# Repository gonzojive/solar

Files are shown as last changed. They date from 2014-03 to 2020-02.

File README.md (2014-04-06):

Introduction
=====

The cost of solar panels has dropped to below $1 per watt.  However, the cost
per installed watt is significantly higher, at over
[$5 / watt in California](http://www.californiasolarstatistics.ca.gov/) in 2014.
This project attempts to provide open source versions of the power electronics in
photovolatic systems, in the hopes that providing such open source hardware
will drive down the price of these components.

The first project is the design of a Maximum Power Point Tracker for a single solar
panel.  A commercial example of this product is the
[SolarEdge series of power optimizers](http://www.solaredge.us/groups/us/powerbox-power-optimizer).

To be continued...

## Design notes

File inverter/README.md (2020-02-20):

# Tim Nolan's grid-tie inverter

The files in this directory were originally developed by Tim Nolan.  I found
them on
[his web site](http://www.timnolan.com/index.php?page=solar-grid-intertie-inverter).

The website is no longer available, and I cannot confirm the license of the original code at this point.

## Project Technical Description

An inverter is basically an electronic device that takes a DC input voltage and
converts it to an AC output voltage. My design takes a 12V DC input from my
solar panels (two 50w panels in parallel) and converts it 120V AC at 60Hz which
is the power that most home appliances use. A grid-intertie inverter connects up
to and external AC power system and matches it's internal AC sinewave to the
external AC sinewave to allow the inverter to feed power into the external
system. My inverter design also includes a maximum power point tracking
algorithm to maximize the power drawn from the solar panel. The inverter uses 4
MOSFETs in a full bridge configuration to convert the input DC to a low voltage
AC. The low voltage AC is converted to high voltage AC by a toroidal transformer
with a 1:30 ratio. The high voltage AC is rectified by 4 diodes in a full bridge
configuration. The resulting waveform is smoothed by an inductor and capacitor
filter and then converted to an AC sinewave by the final 4 MOSFET switches. A
relay is used to connect the generated AC to the external AC. I used an Atmel
AT90PWM3B processor to control the inverter. This processor has some nice
feature that make is well suited to digital power control. Please see the
hardware description and software comments for a more detailed explanation of
the project.

## Schematics

These schematics were created with EagleCAD v4.16r1. I've included the Eagle
schematics and the pdf version of the schematic and the board layout file. This
project is divided into two printed circuit board. The low voltage board (12v
DC) is the inverter control board. The high voltage board (120v AC) is the
inverter power board.

Inverter Control Board:

- `inverter_control.sch`
- `inverter_control.brd`
- `inveter_control.pdf`
- `inverter_control_parts.txt`

Inverter Power Board:

- `inverter_power.sch`
- `inverter_power.brd`
- `inverter_power.pdf`
- `inverter_power_parts.txt`

## Hardware Description

### Low Voltage Section (inverter\_control.sch)

The inverter is divided into two printed circuit board. The `inverter_control.sch`
describes the low voltage circuit board. U4 is the microprocessor. It is an
Atmel AT90PWM3B. I choose the AT90PWM3B because it has a very power and flexible
PWM control section that they call a Power Stage Controller. The processor has a
serial interface to talk to the PC using a MAX232A (IC2) and 9 pin D connector
(X5). The ISP programming connector for the JTAGICE mk II is the 6 pin .1"
(SV4). X4 and Q5 are for PWM fan speed control but this feature is not
implemented yet. S1 dipswitch is for user software configuration and
debugging. U3 is an LM35 analog temperature sensor. This temperature sensor is
mounted next to the MOSFETs on the heatsink. It is used by software to make sure
the MOSFETs don't overheat. IC5 is a 74LS32 Quad OR gate and IC1 is a 74LS14 Hex
Inverter. These gates are used to read back the zero crossing signals from the
high power board. The OR gate is connected to a Timer Input Capture pin so the
length of the zero crossing signal can be calculated. Q1, Q2, Q3 and Q4 are the
MOSFETs (IRLIZ44 N-fets) that make up the full bridge switcher. This is the
heart of the low voltage section. The full bridge switcher takes the DC input
voltage from the solar panels and switches it into high frequency AC to pass on
to the transformer to generate high voltage AC. The MOSFETs are driven by two
IR2104s MOSFET drivers (U1 and U2). The IR2104s use bootstrap capacitors C9 and
C10 to generate the voltages needed to drive the high side MOSFETs Q1 and
Q3. C14 and C15 are the large input capacitors used to smooth out the input
solar power. R32 and R33 make up the voltage divider to drop down the input
solar voltage so it can be read by the processor A/D. IC8 is a LT1787 that use
the current sensing resistor R30 to measure the input solar current. Using the
solar panel voltage and input current the processor can calculate the solar
panel wattage that is used in the Peak Power Tracking algorithm. IC9 is the
linear regulator used to generate 5V from the input solar voltage. SV1 is the
connector for the control and sensing signals to the inverter\_power pcb. X3 is
the connector for the high frequency low voltage AC generated by the full bridge
to the isolation tranformer primary. The transformer is a xxxx ferrite
toriod. The primary is wound with 3 turns of 16ga magnet wire. The secondary is
wound with 60 turns 20ga magnet wire which give the transformer a ratio of
1:20. The transformer also has two more isolated secondary windings of 4
turns. These generate two seperate isolated power supplies for the sensing
circuits on the inverter\_power pcb.

### High Voltage Section (inverter\_power.sch)

The inverter power pcb takes the high frequency high voltage AC from the
transformer and turns it into 120V AC power synced up to the external AC. There
are also isolated sections that sense the zero crossing and the voltage of the
external AC. The low voltage control and sensing signals to and from the
inverter control pcb go through a 16 pin ribbon cable to the SV1 connector. All
the low voltage signals to and from the inverter control board are isolated from
the high voltage AC on the inverter power board by optoisolators. The high
voltage high frequency AC from the transformer secondary comes in on connector
X1. It is snubbed by R14 and C25 and then rectified by 4 diodes in a bridge
configuration D22, D23, D24 and D25. The pcb also has an active rectifier with 4
MOSFETSs Q6, Q7, Q8 and Q9 but these are not used and not installed. Their
MOSFET drivers U8 and U9 and control signal optoisolators OK4A, OK4B and OK5B
are also not used and not installed. After the diode rectifer the signal is
snubbed again by D21, R19 and C32. Then it's smoothed by L2 ad C27. There are
also connectors X5 and X6 so that different values of inductor capacitor filters
can be experimented with. Normally at this point the high frequency and high
voltage AC signal from the transformer secondary would be rectified and smoothed
out to a high voltage DC value. In most inverter topologies this DC voltage
would be chopped and inverted into a 120V 60Hz AC sinewave by the MOSFETs in the
output bridge(Q10, Q11, Q12 and Q13). This means the output MOSFETs have to
switch at a very high frequency (>30kHz) to recreate a sinewave that can be
smoothed by the output filters. Because the MOSFETs are switching a high voltage
at a high switching rate I found in my experimentation that they get very hot. I
went back and did some more research and found a slightly different topology
that alleviated this problem. Instead of a constant duty cycle the low voltage
bridge varies the duty cycle of the high frequency AC in a 60Hz sine wave
pattern. After transformer voltage boost rectification and smoothing instead of
a constant high voltage DC you get a positive only 60Hz sinewave varying voltage
(insert oscilliscope image). Since most of the work of generating the sinewave
is already done the output bridge only as to switch at the 60Hz rate to unfold
the waveform to flip one half of it to negative (insert oscilliscope
picture). Since the output bridge is switching much slower it runs much
cooler. Once the 120V 60Hz AC is generated it can not be connected to the
external grid AC until it is matched in phase and voltage. The relay K1 keeps
the voltage isolated until the processor says it is correct. The output bridge
is driven by two MOSFET drivers U10 and U11. They are isolated from the low
voltage control signals by the optoisolators OK3A, OK3B and OK5A. The MOSFET
drivers and optos are powered by the isolated power supply generated by the
auxilary winding on the transformer AUX1. The winding is connected to X2 and
rectified filtered by B2 and C20. IC7 is the voltage regulator that generates
5v. To sync the interally generated AC to the external AC the zero crossing of
the external AC must be sensed. That's done by the two optoisolators OK2A and
OK2B. Two low voltage signals are generated that bracket the zero crossing of
the external AC. Measuring the external AC voltage and sending it back the
signal isolated to the low voltage side is tricky. I ended up using a small 8
pin Atmel microprocessor the ATtiny45. An isolated power supply was generated
using another isolated winding on the transformer AUX2. This comes in on
connector X4 and is rectified and filtered by B1 and C1. IC3 generates 5V that
is filtered by C11. This 5V is used to power IC4 which is the ATtiny45
microprocessor. SV2 is the programming connector and LED3 is the heartbeat
LED. The external AC is rectified by B3 so we get it all as a positive
signal. Then it is voltage divided and filtered by R10, R11 and C12 so the input
voltage is under 5v to be read by the processor A/D. The processor reads the
input voltage and calculates the RMS AC voltage (see the software listing
sw\_sensev5.c for how this is done). The value of the external AC RMS voltage is
then transmitted as a clocked serial signal through the optoisolators OK1A and
OK1B to get it to the main processor on the isolated low voltage control pcb.

## Software

The main processor for the inverter is an Atmel AT90PWM3B. I used the free
development system from Atmel AVR Studio 4 and installed the open source GCC
compiler package WinAVR. This has allowed me to write all my software for this
project in C using this free development enviroment. I did buy Atmel's JTAGICE
mk II that allows me to download, program and debug the processor in my system
using the in circuit programming port on the processor. I've included the source
code for the AT90PWM3B main processor and the small ATtiny45 processor that used
to read the AC voltage. Please see the comments in the code for explanation of
the inverter software.

AT90PWM3B Main Processor Source Code: `sinewave4v10.c`

ATtiny45 Auxilary Processor Source Code: `sw_sensev5.c`

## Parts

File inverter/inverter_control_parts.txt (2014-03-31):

Partlist

Exported from inverter_control.sch at  1/18/2009 01:41:28p

EAGLE Version 4.16r1 Copyright (c) 1988-2006 CadSoft

Part     Value           Device           Package    Library          Sheet

C1       .1uF            C2,5-3           C2.5-3     capacitor-wima   1
C2       .1uF            C2,5-3           C2.5-3     capacitor-wima   1
C3       .1uF            C2,5-3           C2.5-3     capacitor-wima   1
C4       .1uF            C2,5-3           C2.5-3     capacitor-wima   1
C5       .1uF            C2,5-3           C2.5-3     capacitor-wima   1
C6       .1uF            C2,5-3           C2.5-3     capacitor-wima   1
C7       .1uF            C2,5-3           C2.5-3     capacitor-wima   1
C8       10uF            C5/3.5           C5B3.5     capacitor-wima   1
C9       .1uF            C2,5-3           C2.5-3     capacitor-wima   1
C10      .1uF            C2,5-3           C2.5-3     capacitor-wima   1
C11      .1uF            C2,5-3           C2.5-3     capacitor-wima   1
C12      .1uF            C2,5-3           C2.5-3     capacitor-wima   1
C14      100uF           CPOL-USE5-13     E5-13      rcl              1
C15      100uF           CPOL-USE5-13     E5-13      rcl              1
C16      ,01uF           C2,5-3           C2.5-3     capacitor-wima   1
C17      .1uF            C2,5-3           C2.5-3     capacitor-wima   1
C18      .1uF            C2,5-3           C2.5-3     capacitor-wima   1
D1       1N4148          1N4148           DO35-10    diode            1
D2       1N4148          1N4148           DO35-10    diode            1
IC1      74LS14N         74LS14N          DIL14      74xx-us          1
IC2      MAX232          MAX232           DIL16      maxim            1
IC5      74LS32N         74LS32N          DIL14      74xx-us          1
IC8      LT1787          LT1787           SO08       SolarFlasher     1
IC9      5V              78XXS            78XXS      v-reg            1
LED1     GRN             LED3MM           LED3MM     led              1
LED2     RED             LED3MM           LED3MM     led              1
Q1       IRLIZ44         PMOSFET_NTO220BV TO220BV    transistor-power 1
Q2       IRLIZ44         PMOSFET_NTO220BV TO220BV    transistor-power 1
Q3       IRLIZ44         PMOSFET_NTO220BV TO220BV    transistor-power 1
Q4       IRLIZ44         PMOSFET_NTO220BV TO220BV    transistor-power 1
Q5       2N3904          2N3904           TO92       transistor-npn   1
R1       10k             R-US_0207/10     0207/10    rcl              1
R2       1k              R-US_0207/10     0207/10    rcl              1
R3       1k              R-US_0207/10     0207/10    rcl              1
R4       1k              R-US_0207/10     0207/10    rcl              1
R5       10              R-US_0207/10     0207/10    rcl              1
R30      .005            R-US_0207/12     0207/12    rcl              1
R31      3k              R-US_0207/10     0207/10    rcl              1
R32      3k              R-US_0207/10     0207/10    rcl              1
R33      1k              R-US_0207/10     0207/10    rcl              1
R34      1k              R-US_0207/10     0207/10    rcl              1
S1       DIP2            SD4-02           SD4-02     switch-dil       1
SV1      DUAL8           MA08-2           MA08-2     con-lstb         1
SV4      DUAL3           MA03-2           MA03-2     con-lstb         1
U1       IR2106          IR2103           DIL08      irf-2            1
U2       IR2106          IR2103           DIL08      irf-2            1
U3       LM35            LM35             TO220S     inverter         1
U4       AT90PWM3B_DIP32 AT90PWM3B_DIP32  DIL32      inverter         1
X2       PIN2            W237-02P         W237-132   con-wago-508     1
X3       PIN2            W237-02P         W237-132   con-wago-508     1
X4       22-23-2021      22-23-2021       22-23-2021 con-molex        1
X5       SERIAL          F09HP            F09HP      inverter         1

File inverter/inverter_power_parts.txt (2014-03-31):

Partlist

Exported from inverter_power.sch at  1/18/2009 01:45:12p

EAGLE Version 4.16r1 Copyright (c) 1988-2006 CadSoft

Part     Value          Device           Package  Library          Sheet

B1       DIP4           B-DIL            B-DIL    rectifier        1
B2       DIP4           B-DIL            B-DIL    rectifier        1
B3       DIP4           B-DIL            B-DIL    rectifier        1
C1       100uF          CPOL-USE5-10.5   E5-10,5  rcl              1
C2       .1uF           C2,5-3           C2.5-3   capacitor-wima   1
C3       .1uF           C2,5-3           C2.5-3   capacitor-wima   1
C4       .1uF           C2,5-3           C2.5-3   capacitor-wima   1
C11      10uF           C2,5-3           C2.5-3   capacitor-wima   1
C12      .1uF           C2,5-3           C2.5-3   capacitor-wima   1
C13      .1uF           C2,5-3           C2.5-3   capacitor-wima   1
C19      10uF           C2,5-3           C2.5-3   capacitor-wima   1
C20      100uF          CPOL-USE5-10.5   E5-10,5  rcl              1
C25      .01uF          C5/4.5           C5B4.5   capacitor-wima   1
C27      2uF            C22/8            C22.5B8  capacitor-wima   1
C28      .1uF           C2,5-3           C2.5-3   capacitor-wima   1
C29      .1uF           C2,5-3           C2.5-3   capacitor-wima   1
C30      .1uF           C2,5-3           C2.5-3   capacitor-wima   1
C31      .1uF           C2,5-3           C2.5-3   capacitor-wima   1
C32      .01uF          C5/4.5           C5B4.5   capacitor-wima   1
C34      .1uF           C2,5-3           C2.5-3   capacitor-wima   1
C35      .1uF           C2,5-3           C2.5-3   capacitor-wima   1
C37      .1uF           C2,5-3           C2.5-3   capacitor-wima   1
C38      .1uF           C2,5-3           C2.5-3   capacitor-wima   1
C39      .1uF           C2,5-3           C2.5-3   capacitor-wima   1
C40      .1uF           C2,5-3           C2.5-3   capacitor-wima   1
D3       1N4004         1N4004           DO41-10  diode            1
D4       1N4004         1N4004           DO41-10  diode            1
D17      1N4148         1N4148           DO35-10  diode            1
D18      1N4148         1N4148           DO35-10  diode            1
D19      1N4148         1N4148           DO35-10  diode            1
D20      1N4148         1N4148           DO35-10  diode            1
D21      MUR150RL       MUR150RL         DO41-10  diode            1
D22      FES08AT        FES08AT          DO220S   diode            1
D23      FES08AT        FES08AT          DO220S   diode            1
D24      FES08AT        FES08AT          DO220S   diode            1
D25      FES08AT        FES08AT          DO220S   diode            1
D26      1N4148         1N4148           DO35-10  diode            1
F1       5A             TR5              TR5      fuse             1
F2       5A             TR5              TR5      fuse             1
IC3      5V             78XXS            78XXS    v-reg            1
IC4      TINY45         TINY22P          DIL08    atmel            1
IC7      5V             78XXS            78XXS    v-reg            1
K1       NA             NA               NA       relay            1
L2       400uH          L-USTJ6-U1       TJ6-U1   rcl              1
LED3     GRN            LED3MM           LED3MM   led              1
OK1      HCPL2630       HCPL2630         DIL08    optocoupler      1
OK2      HCPL2630       HCPL2630         DIL08    optocoupler      1
OK3      HCPL2630       HCPL2630         DIL08    optocoupler      1
OK4      HCPL2630       HCPL2630         DIL08    optocoupler      1
OK5      HCPL2630       HCPL2630         DIL08    optocoupler      1
Q6       IRFI740        PMOSFET_NTO220BV TO220BV  transistor-power 1
Q7       IRFI740        PMOSFET_NTO220BV TO220BV  transistor-power 1
Q8       IRFI740        PMOSFET_NTO220BV TO220BV  transistor-power 1
Q9       IRFI740        PMOSFET_NTO220BV TO220BV  transistor-power 1
Q10      IRFI740        PMOSFET_NTO220BV TO220BV  transistor-power 1
Q11      IRFI740        PMOSFET_NTO220BV TO220BV  transistor-power 1
Q12      IRFI740        PMOSFET_NTO220BV TO220BV  transistor-power 1
Q13      IRFI740        PMOSFET_NTO220BV TO220BV  transistor-power 1
R4       10k            R-US_0207/10     0207/10  rcl              1
R5       330            R-US_0207/10     0207/10  rcl              1
R6       4.7k           R-US_0207/10     0207/10  rcl              1
R7       4.7k           R-US_0207/10     0207/10  rcl              1
R8       4.7k           R-US_0207/10     0207/10  rcl              1
R9       1k             R-US_0207/10     0207/10  rcl              1
R10      100k           R-US_0207/10     0207/10  rcl              1
R11      2k             R-US_0207/10     0207/10  rcl              1
R12      20K            R-US_0207/10     0207/10  rcl              1
R13      20K            R-US_0207/10     0207/10  rcl              1
R14      10k            R-US_0617/5V     0617V    rcl              1
R15      330            R-US_0207/10     0207/10  rcl              1
R16      330            R-US_0207/10     0207/10  rcl              1
R17      330            R-US_0207/10     0207/10  rcl              1
R18      330            R-US_0207/10     0207/10  rcl              1
R19      10k            R-US_0617/5V     0617V    rcl              1
R20      4.7K           R-US_0207/10     0207/10  rcl              1
R21      4.7K           R-US_0207/10     0207/10  rcl              1
R22      4.7K           R-US_0207/10     0207/10  rcl              1
R23      4.7K           R-US_0207/10     0207/10  rcl              1
R24      4.7k           R-US_0207/10     0207/10  rcl              1
R25      330            R-US_0207/10     0207/10  rcl              1
R26      4.7K           R-US_0207/10     0207/10  rcl              1
R27      330            R-US_0207/10     0207/10  rcl              1
R28      4.7K           R-US_0207/10     0207/10  rcl              1
R29      330            R-US_0207/10     0207/10  rcl              1
SV1      DUAL8          MA08-2           MA08-2   con-lstb         1
SV2      DUAL3          MA03-2           MA03-2   con-lstb         1
U8       IR2110         IR2103           DIL08    irf-2            1
U9       IR2110         IR2103           DIL08    irf-2            1
U10      IR2110         IR2103           DIL08    irf-2            1
U11      IR2110         IR2103           DIL08    irf-2            1
X1       PIN2           W237-02P         W237-132 con-wago-508     1
X2       PIN2           W237-02P         W237-132 con-wago-508     1
X3       PIN3           W237-3E          W237-3E  con-wago-508     1
X4       PIN2           W237-02P         W237-132 con-wago-508     1
X5       PIN2           W237-02P         W237-132 con-wago-508     1
X6       PIN2           W237-02P         W237-132 con-wago-508     1

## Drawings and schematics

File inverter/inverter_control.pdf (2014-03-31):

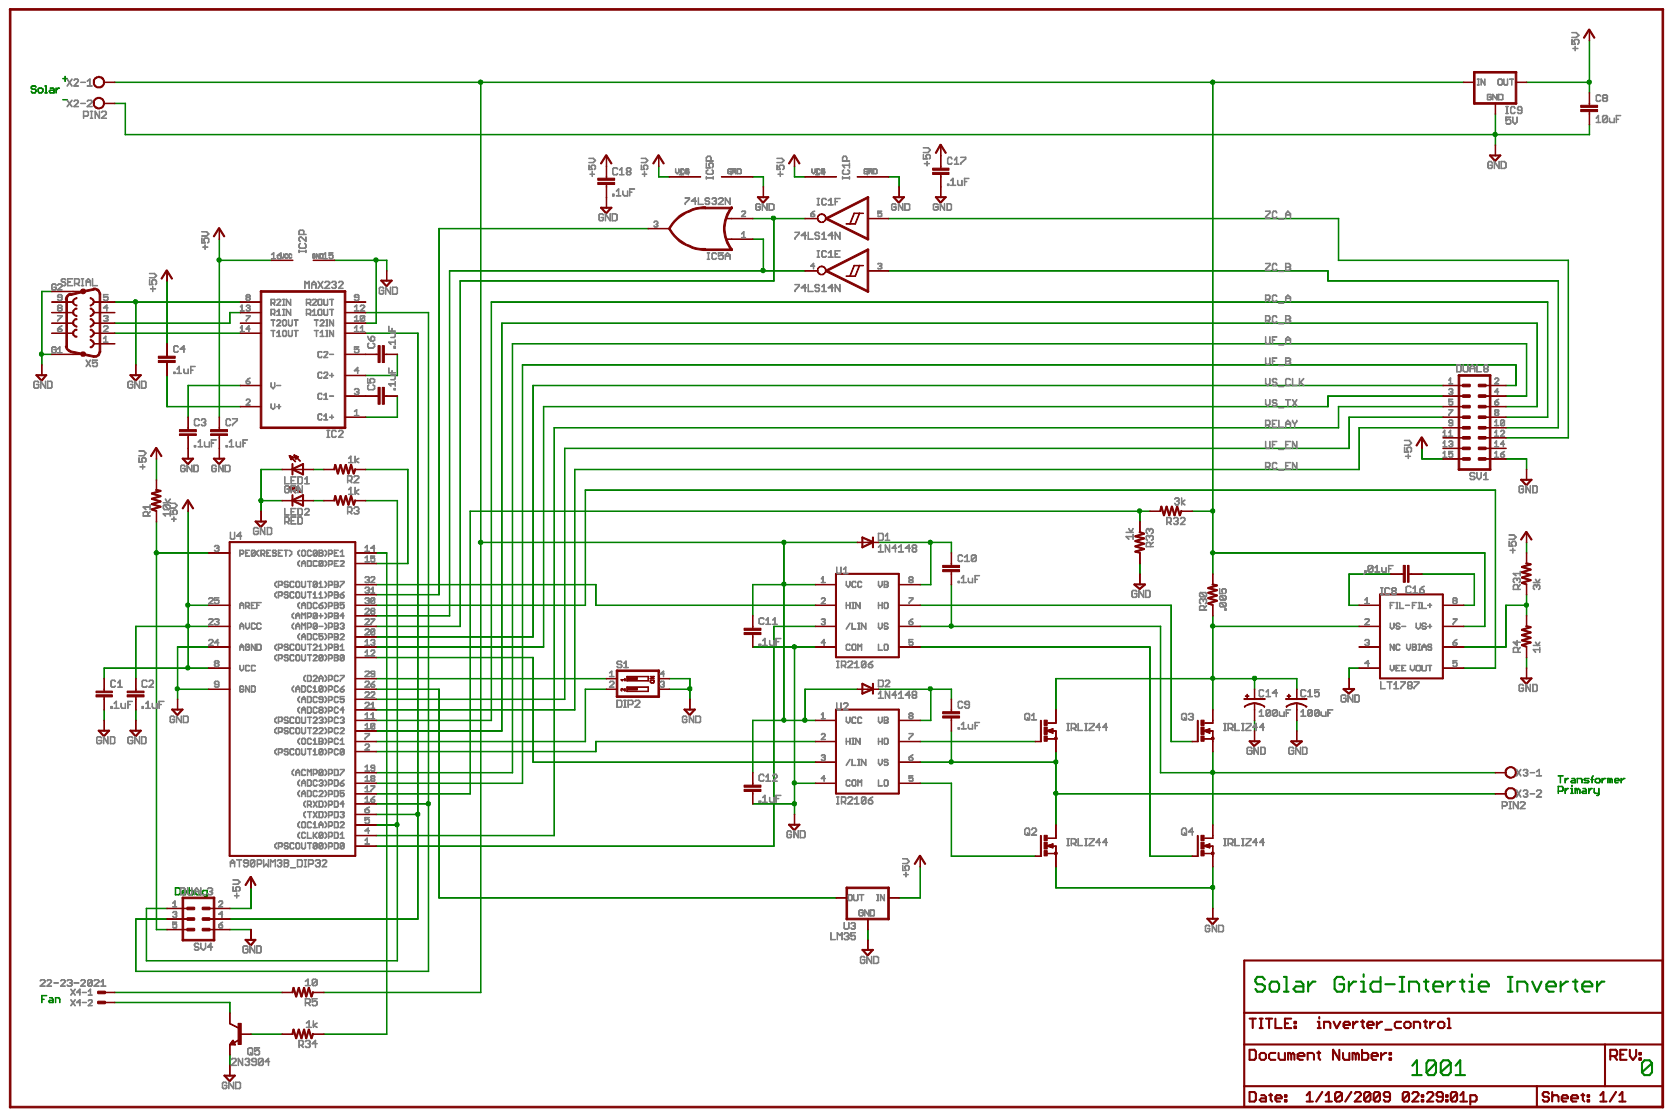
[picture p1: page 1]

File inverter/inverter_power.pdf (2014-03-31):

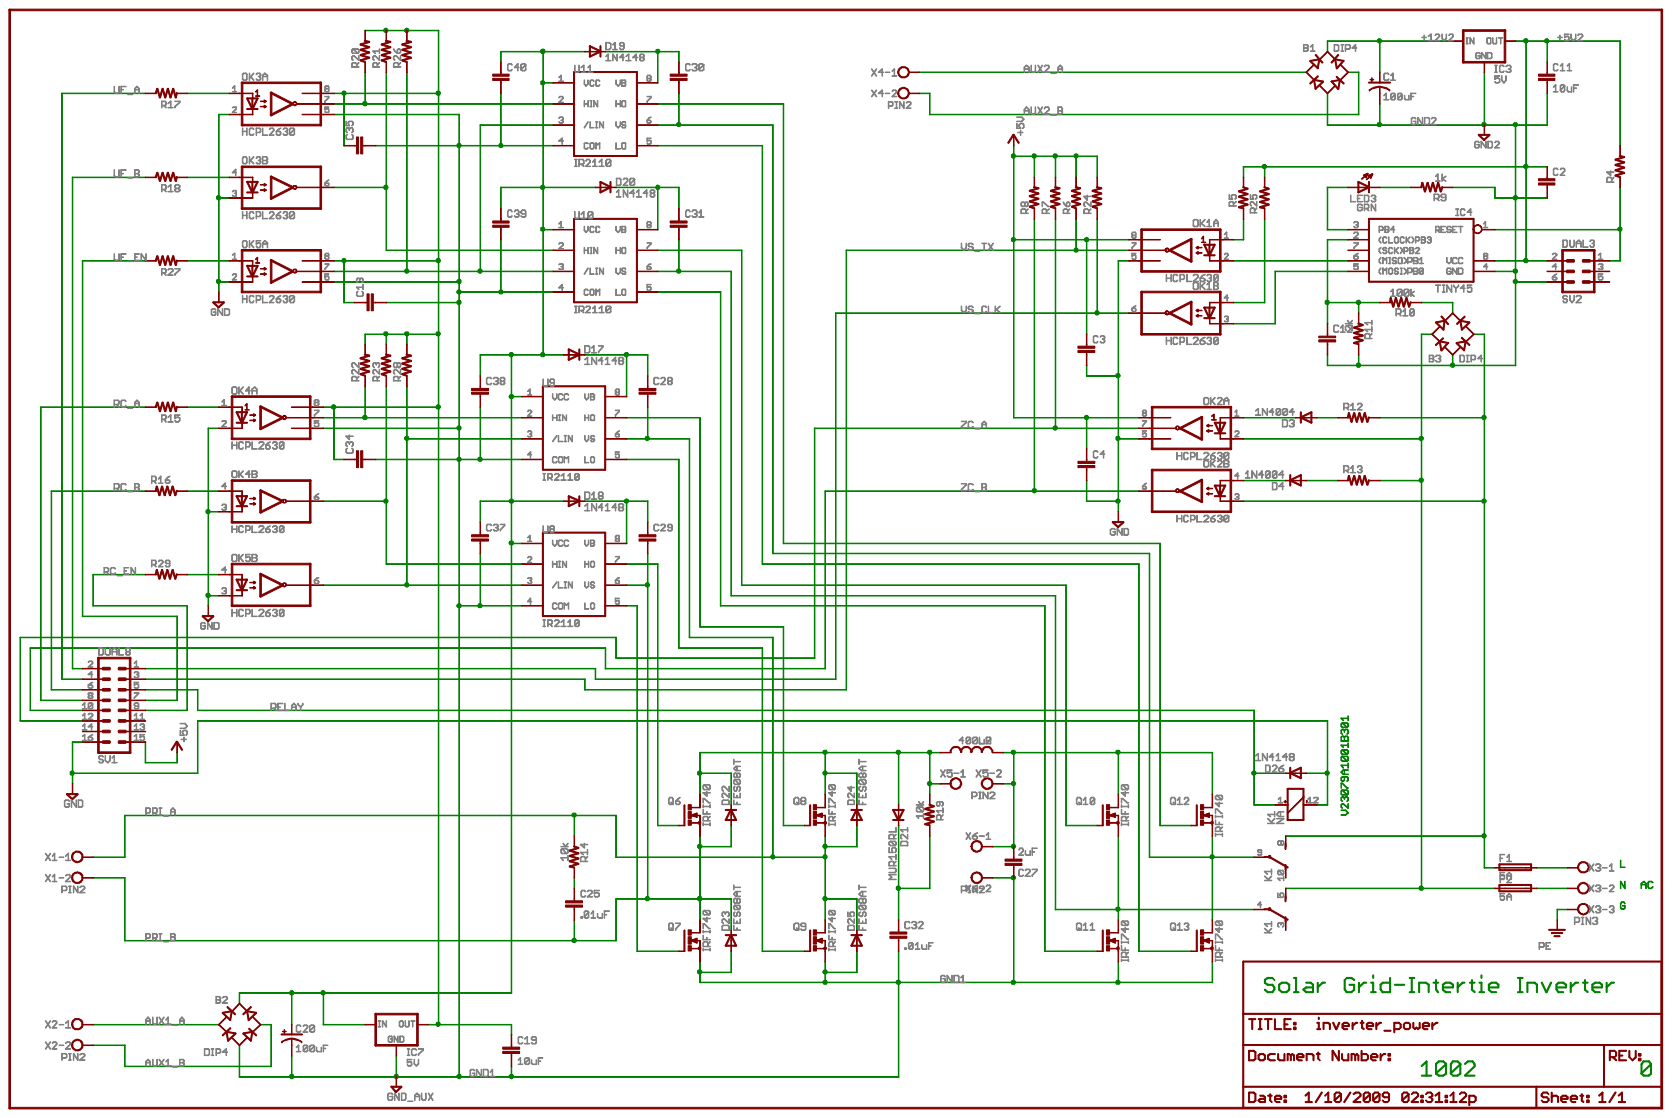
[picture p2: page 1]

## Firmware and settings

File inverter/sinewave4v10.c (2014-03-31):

//---------------------------------------------------------------------------------------------------------------------
/*
 * **** Solar Grid_Intertie Inverter	by Tim Nolan	copyright 2008-2009 	******
 * 
 * 	This is the software for the main AT90PWM3B processor in my solar inverter project.
 * 	I'm releasing this software to the public with no restrictions. If you use it in your project all I ask is a 
 *	credit and a link back to my website www.timnolan.com.	.
 *
 * Fuses should be programmed as 0xF3, 0xDA, 0xF9 for low, high and extended in ISP mode.
 * So set BOD VCC=4.2V and PLL clock 16Mhz; Startup time PWRDWN/RESET 16k CK/14 CK + 0ms
 * and disable CLKDIV. Then program DWEN to get to debug wire mode.
 *
 * v0.01 12/21/07	First try to get something to work.
 *
 * v0.04 8/11/08	Moved into new hardware.
 *
 * v0.10 1/2/09		Added and updated comments for website.
 *
 */
//---------------------------------------------------------------------------------------------------------------------

#include <inttypes.h>
#include <avr\io.h>
#include <interrupt.h>
#include <delay.h>
#include <stdio.h>
#include <ctype.h>
#include <stdlib.h>
#include <string.h>

//#define START_STR "Solar Inverter by Tim Nolan  Copyright 2008 "
//#define VERS "v0.01"									// change version number for each version of code release
#define BAUD9600  103 									/* Run the UART at 9600 baud @16MHz fosc. */
#define TRUE 1
#define FALSE 0
#define ON 1
#define OFF 0
#define SETPOINT 500
#define KD 1
#define F60HZ 4166
#define F60HZ64 65
#define F60HZMAX 4267
#define F60HZMIN 4067
#define FSETPOINT 2180
#define FSETPOINT2 0
#define ASETPOINT 300
#define FREQ_SCALE 100000000
//#define FREQ_SCALE 102000000
#define USEC_INC 4
#define ADJ_START 100
#define ADJ_MIN 95
#define ADJ_MAX 205
#define AMP_START 58
#define ADJ16_START 120		
#define ADJ16_MIN 100
#define ADJ16_MAX 1000
#define INC_HI 5
#define INC_LO 2
#define MIN_DC_AMPS 10
#define MAX_DC_AMPS 500
#define FAULT_MAX_DC_AMPS 600
#define FAULT_MIN_DC_AMPS 0
#define MIN_DC_VOLTS 1200
#define MAX_DC_VOLTS 2000
#define FAULT_MIN_DC_VOLTS 1150
#define FAULT_MAX_DC_VOLTS 2200
#define MIN_ADJ16 130
#define MAX_ADJ16 1000
#define ADJ_INC_POS 10
#define ADJ_INC_NEG -10
#define MIN_FREQ 54
#define MAX_FREQ 66
#define MIN_AC_VOLTS 108
#define MAX_AC_VOLTS 132
#define FAULT_SECONDS 5

#define TURN_ON	{PORTC &= ~(_BV(PORTC4) | _BV(PORTC5)); PCTL2 = _BV(PRUN2); pp_switch = ON;} 	
															/*enable UF_EN and RC_EN by setting PC4 and PC5 low*/	
						    								/*start power state timers*/
#define TURN_OFF {PORTC |= (_BV(PORTC4) | _BV(PORTC5)); PCTL2 &= ~_BV(PRUN2); pp_switch = OFF;}	
															/*disable UF_EN and RC_EN by setting PC4 and PC5 high*/	
															/*stop power stage timers*/

//------------------------------------------------------------------------------------------
// Function prototypes
//------------------------------------------------------------------------------------------
void update_adj(int16_t);
uint8_t check_faults(void);
//int16_t fir(uint16_t);
void ioinit (void); 
uint8_t kbhit(void); 
int uart_getchar(void);
int uart_putchar(unsigned char);

//------------------------------------------------------------------------------------------
// Global variables
//------------------------------------------------------------------------------------------
// 1/2 sinewave table full 8 bit swing					
 uint8_t const pwmtab[32]={25,50,74,98,120,142,162,180,197,212,	
 225,235,244,250,254,255,254,250,244,235,				
 225,212,197,180,162,142,120,98,74,50,25,0};				

enum { POS, NEG };
enum { VOLT, AMP, TEMP };
enum pp_states { WAIT, SYNC, PP_ON, PP_TRACK, PP_SWEEP, PP_DOWN, PP_OFF, PP_FAULT, NIL } state;

volatile uint8_t polarity;
volatile uint8_t adc_type;
volatile uint8_t index1;

uint16_t temp;
uint16_t bps;
uint16_t shift;
uint16_t counter;
uint16_t pwm;
uint8_t pwm_temp;
uint8_t pwm_adj;
uint8_t adj = ADJ_START;
uint16_t temp16;
uint32_t temp32;
uint8_t temp_msb;
uint8_t temp_lsb;
int16_t error;
int16_t adj16 = ADJ16_START;
int16_t error_sum;
uint8_t tcount;
uint8_t tindex;
int16_t comp1a_max = F60HZ;					
int16_t comp1b_inc;
int16_t comp1b_prev;
int16_t edge_temp;
int16_t edge1;
int16_t edge2;
int16_t edge_neg;
int16_t edge_pos;
uint8_t edgeh;
uint8_t edgel;
int16_t freq_error;
int16_t freq_error_sum;
int8_t	ac_count = 10;
uint8_t phase_lock;
uint8_t ac_good;
uint8_t sweep;
uint8_t down;
uint8_t pp_track;
uint8_t fault;
int16_t freq;
int16_t freq_dsp;
int32_t adc_result;
int16_t prev;
int32_t adc_sum;
int16_t watts;
int16_t watts_prev;
int8_t inc = INC_HI;
int8_t  delta = INC_HI;
uint8_t grid_intertie;
int16_t dc_volts;
int16_t dc_amps;
int16_t watts_filt;
uint8_t keypress;
uint16_t ext_ser_in;
uint16_t timer1;
uint16_t ac_volts;
uint16_t tenth_seconds;
uint16_t seconds;
uint16_t prev_seconds;
uint16_t wait_fault_seconds;
uint16_t wait_seconds;
uint8_t pp_switch;
int16_t temperature;


//----------------------------------------------------------------------------------------------------
// This is fixed point FIR filter routine designed by WinFilter software. It is not used currently.
//
//WinFilter version 0.8
//http://www.winfilter.20m.com
//akundert@hotmail.com
//
//Filter type: Low Pass
//Filter model: Butterworth
//Filter order: 2
//Sampling Frequency: 100 Hz
//Cut Frequency: 2.000000 Hz
//Coefficents Quantization: 16-bit
//
//Z domain Zeros
//z = -1.000000 + j 0.000000
//z = -1.000000 + j 0.000000
//
//Z domain Poles
//z = 0.911347 + j -0.081409
//z = 0.911347 + j 0.081409
//----------------------------------------------------------------------------------------------------
/*
#define Ntap 15

#define DCgain 262144

int16_t fir(uint16_t NewSample) {
    uint16_t FIRCoef[Ntap] = { 
        11143,
        12796,
        14610,
        16594,
        18754,
        21093,
        23616,
        24924,
        23616,
        21093,
        18754,
        16594,
        14610,
        12796,
        11143
    };

    static uint16_t x[Ntap]; 			//input samples
    volatile uint32_t y;		            //output sample
    uint8_t n;
    									//shift the old samples
    for(n=Ntap-1; n>0; n--) {
       x[n] = x[n-1];
	}
    									//Calculate the new output
	y = 0;
    x[0] = NewSample;
    for(n=0; n<Ntap; n++) {
        y += (uint32_t)FIRCoef[n] * (uint32_t)x[n];
	}
    
    return((int16_t)(y / DCgain));
}
*/
//----------------------------------------------------------------------------------------------------
// This interrupt is the timer1 edge capture.
// It occurrs shortly before and shortly after zero crossing.
// Zero crossing is calculated as halfway between the two interrupts.
// The hardware is set up with two opto-isolators connected to the external AC power. They are set up
// so that one is asserted during the positive half of the AC waveform and the other one is asserted 
// during the negative half of the AC waveform. Each opto is connected to an input pin (B3 and B4) so 
// the processor can tell which half of the AC waveform is occuring. At the zero crossing point the LED in the
// opto won't come on until the AC voltage is at least 2V or 3V higher than zero (or lower in the case of
// the negative half of the AC waveform). So what you have is one opto going off right before the zero crossing
// and the other opto coming on right after the zero crossing. The two signals are ORed together and 
// connected to the timer input pin ICR1. Then the time it takes from the turn off before the zero crossing
// until the turn on after the zero crossing is measured by the processor. That time is divided by two
// and that gives you the time of the zero crossing.
// Timer1 is timing the length of 1 AC cycle which is 16.66ms or about 4166 counts on timer1 the way
// the timer is set up. So the times of the zero crossing are between 0 and 4166. 
// This routine calculates the time of edge1 and edge2 the which are the two zero crossing times. The times are 
// based on the time of the AC cycle which is nominally 4166 counts of timer1. The length of the cycle is stored
// in the variable comp1a_max. 
//
//----------------------------------------------------------------------------------------------------
ISR(TIMER1_CAPT_vect) {

	edgel = ICR1L;
	edgeh = ICR1H;												//read in both halves of the timer register
	edge_temp = (edgeh << 8) | edgel;							//get 16 bit timer value in edge_temp
	if (bit_is_clear(TCCR1B,ICES1)) {							//check bit to see if we are reading negative edge of zero cross
   		_delay_loop_2(4*60);									//30us (range 1uS to 16384uS)
		if (bit_is_clear(PINB,PINB6)) edge_neg = edge_temp;		//check bit for debouncing, if low then copy time for neg edge
		else return;											//else if not low then input is bouncing so jump out.
		TCCR1B |= _BV(ICES1);									//set ICES1 bit to detect positive edge for the next interrupt
		TIFR1 |= _BV(ICF1);										//clear the Input Capture Flag for the next interrupt
	}
	else if (bit_is_set(TCCR1B,ICES1)) {						//else check bit to see if we are reading positive edge of zero cross
   		_delay_loop_2(4*60);									//30us (range 1uS to 16384uS)
		if (bit_is_set(PINB,PINB6)) edge_pos = edge_temp;		//check bit for debouncing if set then copy time for positeve edge
		else return;											//if not then bouncing so jump out
		TCCR1B &= ~_BV(ICES1);									//clear ICES1 bit to detect negative edge for next interrupt
		TIFR1 |= _BV(ICF1);										//clear the Input Capture Flag for the next interrupt	
		if (bit_is_set(PINB,PINB4)) {							//check to see if begining of negative AC wave is called edge1
			if ((edge_pos - edge_neg) >= 0) {					//make sure edge_pos comes after edge_neg
				edge1 = ((edge_pos - edge_neg) / 2) + edge_neg;	//calculate time of zero cross by dividing time between edges by two
			}													//and adding it the negative edge to get the time in the cycle
			else {												//else the zero cross ocurs during the rollover of 4166 back to zero
				edge1 = (((comp1a_max - edge_neg) + edge_pos) / 2) + edge_neg;	//so take care of it (comp1a_max is the length of the cycle = 4166)
				if (edge1 > comp1a_max) edge1 = edge1 - comp1a_max; 
			}
		}
		else if (bit_is_set(PINB,PINB3)) {						//check to see if it is the begining of the positive AC waveform called edge2
			if ((edge_pos - edge_neg) >= 0) {					//make sure edge_pos comes after edge_neg
				edge2 = ((edge_pos - edge_neg) / 2) + edge_neg;	//calculate time of zero cross by dividing time between edges by two
			}													//and adding it the negative edge to get the time in the cycle (0-4166)
			else {												//else the zero cross ocurs during the rollover of 4166 back to zero
				edge2 = (((comp1a_max - edge_neg) + edge_pos) / 2) + edge_neg;	//so take care of it (comp1a_max is the length of the cycle = 4166)
				if (edge2 > comp1a_max) edge2 = edge2 - comp1a_max; 
			}
		}
	}
	ac_count = 10;												//this counter is set each time we get a zero cross
}																//if we stop having zero crossing then we time out and say no AC
//----------------------------------------------------------------------------------------------------
// This interrupt occurs once per every 60Hz AC cycle or once every 16.66ms.
// Timer1 is set up so that it is 4166 counts for one AC cycle or 16,66ms. This is the constant F60HZ, the actual value is comp1a_max.
// To keep the internal AC waveform synced up to the external AC waveform this count can change to change the length of internal AC
// cycle. I change the count using a software phase lock loop. The phase lock loop has a software PI controller in the feedback path.
// The PI controller (proportional and integral terms not using derivitive term of PID conroller) takes the error between the external
// and internal AC waves and calculates a new wave length (count for timer1) for the internal AC to keep it synced up to the external
// AC. So the even though the length of timer1 is nominally 4166 (F60HZ) the value in comp1a_max is constantly varying to keep the 
// internally generated AC waveform synced up to the external AC waveform.
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
int main (void)  {        

	uint16_t led_count = 0;
	uint8_t wait_state_count = 0;

    ioinit();
	state = WAIT;
	fault = 0;
	TURN_OFF;								

    do {											/* loop forever */
		if (++led_count & 0x8000) {					//blink green led
      	    PORTE |= _BV(PORTE2);
			}
      	else {
        	PORTE &= ~_BV(PORTE2);
		}

    	if (kbhit()) {
				keypress = uart_getchar();			// get it in keypress
		}

 		if(seconds != prev_seconds) {				//once every second check the system state

	   		switch(state) {
    		case WAIT :								//start in wait state
				adj16 = ADJ16_START;
				if (wait_state_count-- > 0) {
					state = WAIT;					//stay in wait state for 5 seconds
				}
				else if (dc_volts > 1400) {			//if the solar panel dc volts is high enough (daytime)
					state = SYNC;					//move to sync state  
					grid_intertie = TRUE;			//sync to external AC
					TURN_ON;						//turn on MOSFET drivers
				}
				else {
					state = WAIT; 					//else if not daytime yet go back to wait state
				}
	       		break;
    		case SYNC :								
				if (check_faults()) {				//check for faults
					state = PP_FAULT;				//and go to fault state if there is faults
					TURN_OFF;						//turn off MOSFET drivers
				}
				else if (ac_good & phase_lock) {	//else if we have external ac and sycned up 
					state = PP_TRACK;				//then go to tracking state
					PORTD &= ~_BV(PORTD1);       	//relay ON flipped because using hc14 for extra current to drive relay
				}
				else { 
					state = SYNC; 					//else go back to sync
				}
	        	break;
    		case PP_ON :				
				if (check_faults()) {				//check for faults
					state = PP_FAULT;				//go to fault state if faults
					TURN_OFF;						//turn off MOSFET drivers
				}									//else go to state depending on keypress input from serial port
				else if (keypress == 'i') {			
					update_adj(ADJ_INC_POS);
				}
   				else if (keypress == 'j') {
					update_adj(ADJ_INC_NEG);
				}
   				else if (keypress == 's') {
					state = PP_SWEEP;
				}
    			else if (keypress == 'd') {
					state = PP_DOWN;
				}
   				else if (keypress == 'a') {
					state = PP_TRACK;
				}
   				else if (keypress == 'z') {
					state = PP_OFF;
				}
				else {
					state = PP_ON;
				}
				break;
	    	case PP_TRACK :									// the track function is taken care of in the 60hz interrupt to get a faster update rate				
				if (check_faults()) {
					state = PP_FAULT;
					TURN_OFF;								//turn off MOSFET drivers
				}
		    	else if (keypress) {
					state = PP_ON; 
				}
				else {
					state = PP_TRACK;
				}
    	    	break;
    		case PP_DOWN :				
				update_adj(-INC_HI);						//in PP_DOWN state sweep the overall adjust value down 
				if (check_faults()) {						//this is for debugging purposes
					state = PP_FAULT;
					TURN_OFF;								//turn off MOSFET drivers
				}
	    		else if (keypress) {
					state = PP_ON; 
				}
				else {
					state = PP_DOWN;
				}
        		break;
	    	case PP_SWEEP :									//in PP_SWEEP state sweep the overall adjust value UP 
				update_adj(INC_HI);							//this is for debugging purposes
				if (check_faults()) {
					state = PP_FAULT;
					TURN_OFF;								//turn off MOSFET drivers
				}
		    	else if (keypress) {
					state = PP_ON; 
				}
				else {
					state = PP_SWEEP;
				}
    	    	break;
    		case PP_OFF :				
				TURN_OFF;								//turn off MOSFET drivers
				PORTD |= _BV(PORTD1);					//relay = OFF;
		    	if (keypress) {
					state = WAIT; 
					wait_state_count = 5; 
				}
				else {
					state = PP_OFF;
				}
        		break;
	    	case PP_FAULT :				
				TURN_OFF;								//turn off MOSFET drivers
				PORTD |= _BV(PORTD1);					//relay = OFF;			
				state = WAIT;
				wait_state_count = 5; 
				fault = FALSE;
        		break;
			default :								// keys to make them lower case so this makes	
    		break;									// ESC into 0x3B instead of 0x1B
			}  	//end case

			print_results();						//print output
			prev_seconds = seconds;
			keypress = 0;
		}


    } while(1);

    return (0);
}

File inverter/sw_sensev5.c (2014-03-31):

/*----------------------------------------------------------------------------------------------------------------------*/
/*
 * **** Solar Grid_Intertie Inverter	by Tim Nolan	copyright 2008-2009 	******
 * 
 * 	This is the software for the auxilary ATtiny45 processor in my solar inverter project.
 * 	I'm releasing this software to the public with no restrictions. If you use it in your project all I ask is a 
 *	credit and a link back to my website www.timnolan.com.	.
 *
 * Fuses should be programmed as 0xC2, 0xDC, 0xFF for low, high and extended in ISP mode.
 * So set BOD VCC=4.3V and Int. RC Osc. 8Mhz; Startup time PWRDWN/RESET 6k CK/14 CK + 0ms
 * and disable CLKDIV8. Then program DWEN to get to debug wire mode.
 *
 * v0.04 8/11/08	Moved into new hardware.
 *
 * v0.5 1/2/09		Added and updated comments for website.
 *
 */
/*----------------------------------------------------------------------------------------------------------------------*/


#include <inttypes.h>
#include <io.h>
#include <interrupt.h>
#include <delay.h>

#include <stdio.h>
#include <ctype.h>
#include <stdlib.h>
#include <string.h>

#define DEL 1				//define time delay for spi output
#define NUM 2				//number of average
#define SAMPLES 64
#define TRUE 1
#define FALSE 0
#define SCALE 5

/*---------------------------------------------------------------------*/
// Global variables
/*---------------------------------------------------------------------*/

	uint16_t adc_result, adc_temp, rms_volts;
	uint8_t temp_lsb, temp_msb;
	uint8_t temp_in;
	uint8_t test;
	int32_t adc_sum;
	uint8_t ser_out;

/*----------------------------------------------------------------------*/
// Simple Interger square root function  				
/*----------------------------------------------------------------------*/
uint16_t int_sqrt(uint32_t a){

	uint32_t x = 1;

	while((x * x) < a) {
    	x++;
	}

	return((uint16_t)x); 
}
/*---------------------------------------------------------------------*/
// More efficient square root function.

uint16_t int_sqrt2(uint32_t a) {

	uint32_t square = 1;
	uint32_t delta = 3;
	
	while(square <= a){
    	square += delta;
    	delta += 2;
	}

    return((uint16_t)(delta/2 - 1));
} 
/*-------------------------------------------------------------------*/
/* clock serial output of 10 bits */
void send_10bits(uint16_t cc) {

	uint16_t ser_out;
	uint8_t i;
	uint8_t clock=0;

	ser_out = 0xF800 | (cc << 1);
	for (i=0; i<12; i++) {
		if(ser_out & 0x01) PORTB |= _BV(PORTB1);
		else PORTB &= ~_BV(PORTB1);
		ser_out >>= 1;
		if(clock++ & 0x01) PORTB |= _BV(PORTB0);
		else PORTB &= ~_BV(PORTB0);
		_delay_loop_2(2*48);						// hand tweaked to get 104uS bit times for 9600 baud (range 1uS to 16384uS)
		if(clock++ & 0x01) PORTB |= _BV(PORTB0);
		else PORTB &= ~_BV(PORTB0);
		_delay_loop_2(2*48);						
	}
}
/*---------------------------------------------------------------------*/
// This interrupt occurs every 260uS so we get 64 interrupts in during one AC waveform or 16.66ms.
// We get a sample from the adc every interrupt and sum them so we have 64 ac voltage samples over one complete
// ac waveform. We divide by 64 to get the average AC voltage and take the square root to get RMS AC voltage.
//
ISR(TIM1_OVF_vect) {

	uint8_t templ, temph, temp8;
	static uint8_t count = 0;
	uint16_t temp16;
	uint16_t result;
	static uint16_t prev=0;

	if (count < SAMPLES) {							//if we are still counting
		ADCSRA |= _BV(ADSC);						//start next conversion
		loop_until_bit_is_clear(ADCSRA, ADSC);		//wait until conversion is done
		templ = ADCL;
		temph = ADCH;
		temp16 = (temph << 8) | templ;				//get 16 bit adc result in temp16
		adc_sum += (int32_t)temp16 * (int32_t)temp16;	//keep a running sum over 64 ac volts samples
		count++;
	}
	else {											//when we have gotten 64 samples calculate rms ac volts
	   	PORTB |= _BV(PORTB2);
		rms_volts = int_sqrt2(adc_sum / SAMPLES);	//divide the sum by number of sample to get average and 
		count = 0;									//take the square root to get the rms voltage
		adc_sum = 0;
		result = (rms_volts / 4) + ((prev * 3) / 4);//filter the result to smooth it.
		prev = result;
		send_10bits(result);						//send out the result as a 10 bit serial stream.
	    PORTB &= ~_BV(PORTB2);		
	}
}
/*---------------------------------------------------------------------*/
/*---------------------------------------------------------------------*/
void ioinit (void) 
{
    DDRB = _BV(PORTB4) | _BV(PORTB2) | _BV(PORTB1) | _BV(PORTB0);		 
    PORTB |= _BV(PORTB4);										//turn on green led 

	ADMUX = _BV(MUX1) | _BV(MUX0); 								// set external 5v ref, use ADC3(PB3) input
	ADCSRA = _BV(ADEN) | _BV(ADSC) | _BV(ADPS2) | _BV(ADPS1); 	// enable A/D, start conversion, prescaler divide by 64
	DIDR0 = _BV(ADC3D);											// disable input register on ADC3
																// setup timer1
	TCCR1 = _BV(CTC1) | _BV(PWM1A) | _BV(CS12) | _BV(CS10);		// clear clock on OCR1C match, set pwm mode, clk/16
	OCR1C = 130;												// set timer period
	TIMSK = _BV(TOIE1);											// set timer overflow interrupt

    sei ();														/* enable interrupts */
}

/*----------------------------------------------------------------------*/
int main (void)  {        

	uint16_t led_count=0;

    ioinit();

    do {							/* loop forever */

       if (++led_count & 0x4000) 
          PORTB |= _BV(PORTB4);		//blink the LED
       else
          PORTB &= ~_BV(PORTB4);

	} while(1);

    return (0);
}
